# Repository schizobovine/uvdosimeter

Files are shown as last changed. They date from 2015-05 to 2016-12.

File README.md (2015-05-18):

# UV Dosimeter

Microcontroller project to (somehow) get data from the SiLabs SI1145 UV index
sensor to a user such that they know when the daystar is out to kill them
(slowly, with cancer).

Various designs in the works, but the primary focus right now is a Bluetooth
4.0+ LE based sensor which communicates to a smart phone or watch for data
logging and handling any user interaction/warnings. This cuts out the need for
a display, controls (beyond a power switch), and notification system.

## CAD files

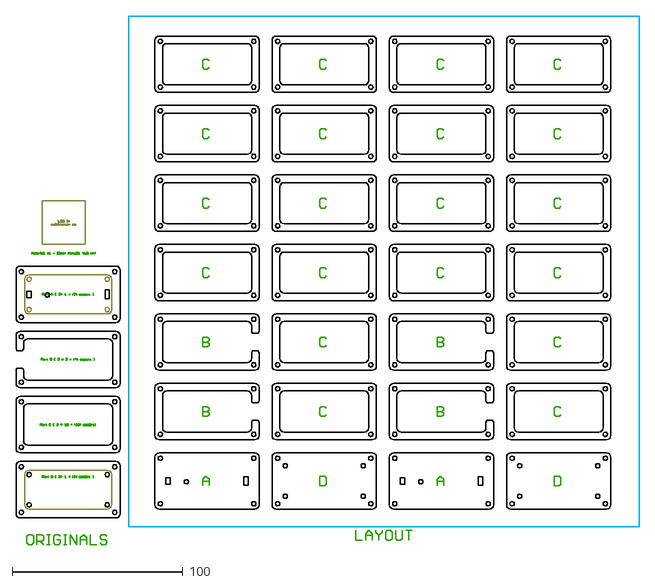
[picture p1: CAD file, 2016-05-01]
hardware/uv-dosimeter-featherwing-case-clear-pmma-1.5mm-mk-1.0.dxf
364.5 x 308.9

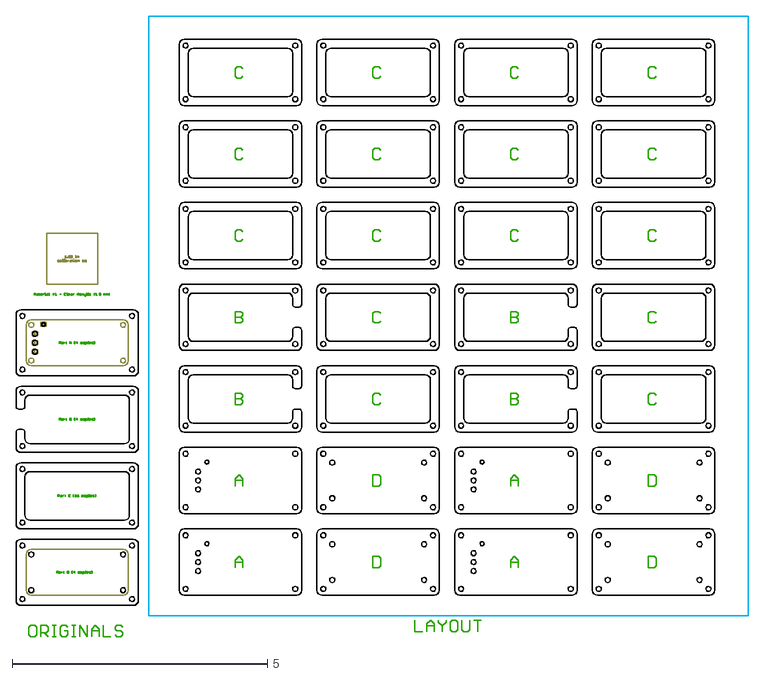
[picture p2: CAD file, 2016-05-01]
hardware/uv-dosimeter-featherwing-case-clear-pmma-1.5mm-mk-2.0.dxf
14.3 x 12.2

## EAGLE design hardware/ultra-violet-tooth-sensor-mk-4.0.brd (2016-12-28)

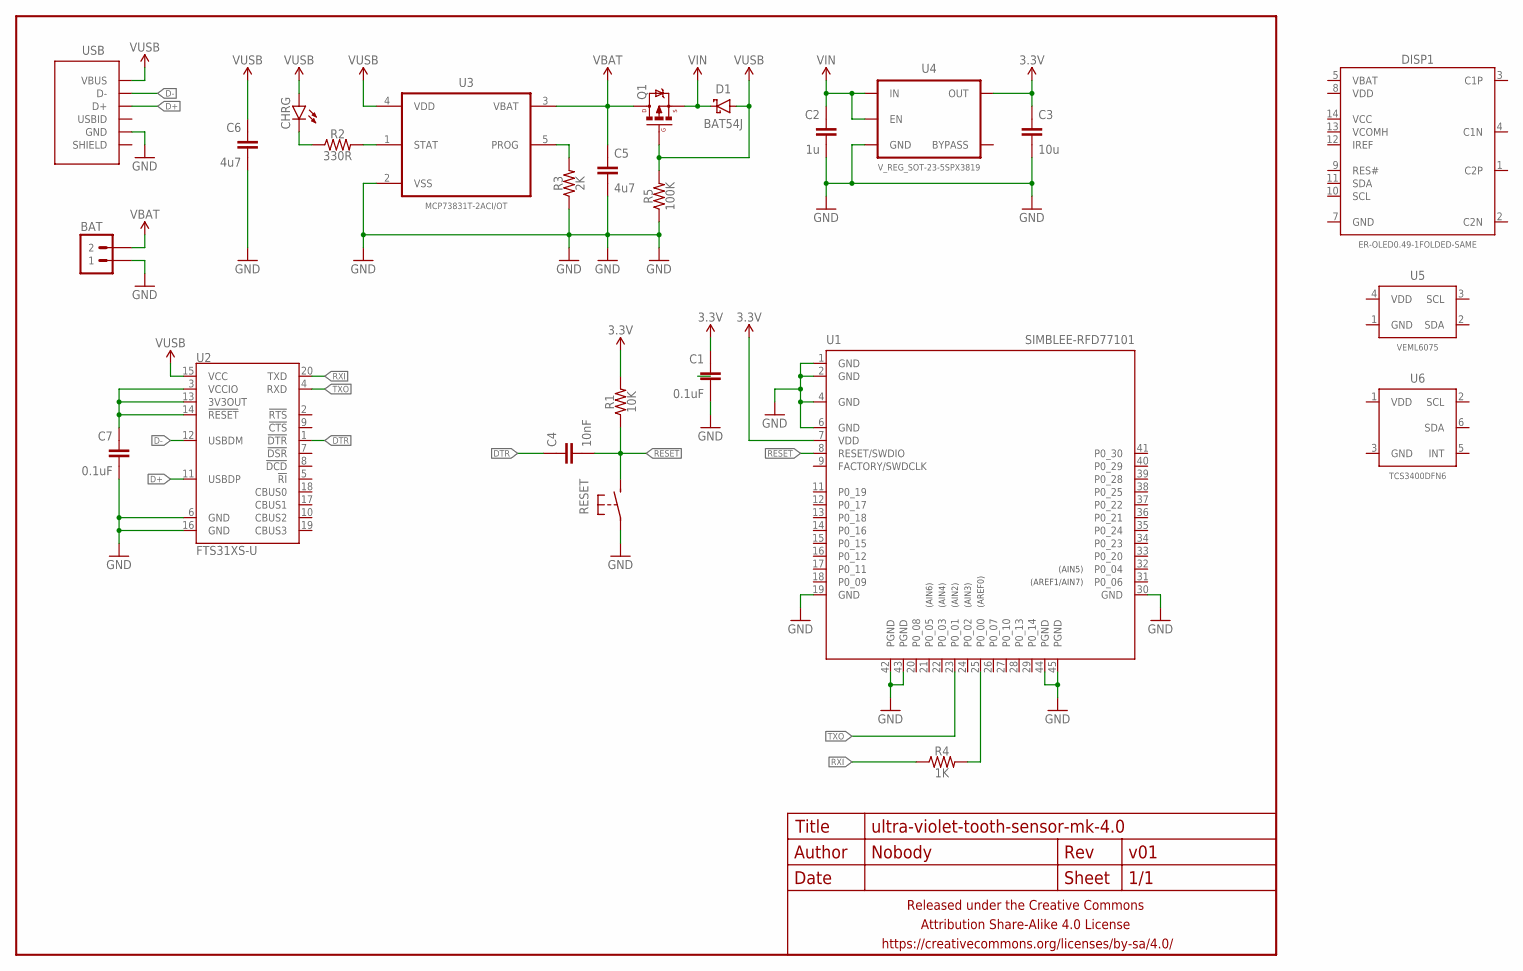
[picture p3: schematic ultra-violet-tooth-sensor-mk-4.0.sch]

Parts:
BAT: M02JST-2MM-SMT; JST-2-SMD
C1, C7: 0.1uF; C0402
C2: 1u; C0603-TIGHTER
C3: 10u; C0603-TIGHTER
C4: 10nF; C0402
C5, C6: 4u7; C0603-TIGHTER
CHRG: LED0603-TIGHT; LED-0603-TIGHT
D1: BAT54J; SOD323-SCHOTTKY
DISP1: ER-OLED0.49-1FOLDED-SAME; ER-OLED0.49-1-FOLDED-SAME
FRAME1: FRAME-LETTERNO_PACKAGE; DUMMY
Q1: MOSFET-PCHANNELSOT-23; SOT23
R1: 10K; R0402
R2: 330R; R0402
R3: 2K; R0402
R4: 1K; R0402
R5: 100K; R0402
RESET: SPST-NO-TACTSMD-TINIER; TACTILE_SWITCH_SMD_TINY
U1: SIMBLEE-RFD77101; RFD77101
U2: FTS31XS-U; SSOP20_L
U3: MCP73831T-2ACI/OT; SOT95P280X145-5N
U4: V_REG_SOT-23-5SPX3819; SOT23-5
U5: VEML6075; OPLGA4
U6: TCS3400DFN6; TCS3400_DFN6
USB: USB-AB-SHIELDFCI-10118193-USB-MICRO-B; FCI-10118193-USB-MICRO-B

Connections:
3.3V: C1.1, C3.1, R1.2, U1.7 (VDD), U4.5 (OUT)
!RESET: C4.2, R1.1, RESET.P$2 (2), U1.8 (RESET/SWDIO)
D+: U2.11 (USBDP), USB.3 (D+)
D-: U2.12 (USBDM), USB.2 (D-)
DTR: C4.1, U2.1 (!DTR)
GND: BAT.2 (1), C1.2, C2.2, C3.2, C5.2, C6.2, C7.2, R3.1, R5.1, RESET.P$1 (1), U1.1 (GND), U1.2 (GND), U1.4 (GND), U1.6 (GND), U1.19 (GND), U1.30 (GND), U1.42 (PGND), U1.43 (PGND), U1.44 (PGND), U1.45 (PGND), U2.6 (GND), U2.16 (GND), U3.2 (VSS), U4.2 (GND), USB.5 (GND)
unnamed: CHRG.C, R2.1
unnamed: R4.2, U1.25 (P0_00)
unnamed: C7.1, U2.3 (VCCIO), U2.13 (3V3OUT), U2.14 (!RESET)
unnamed: R3.2, U3.5 (PROG)
unnamed: R2.2, U3.1 (STAT)
RXI: R4.1, U2.20 (TXD)
TXO: U1.23 (P0_01), U2.4 (RXD)
VBAT: BAT.1 (2), C5.1, Q1.3 (D), U3.3 (VBAT)
VIN: C2.1, D1.C, Q1.2 (S), U4.1 (IN), U4.3 (EN)
VUSB: C6.1, CHRG.A, D1.A, Q1.1 (G), R5.2, U2.15 (VCC), U3.4 (VDD), USB.1 (VBUS)

Board: 2 copper layers, 26 parts (1 on the bottom side), 16 nets, no tracks yet.

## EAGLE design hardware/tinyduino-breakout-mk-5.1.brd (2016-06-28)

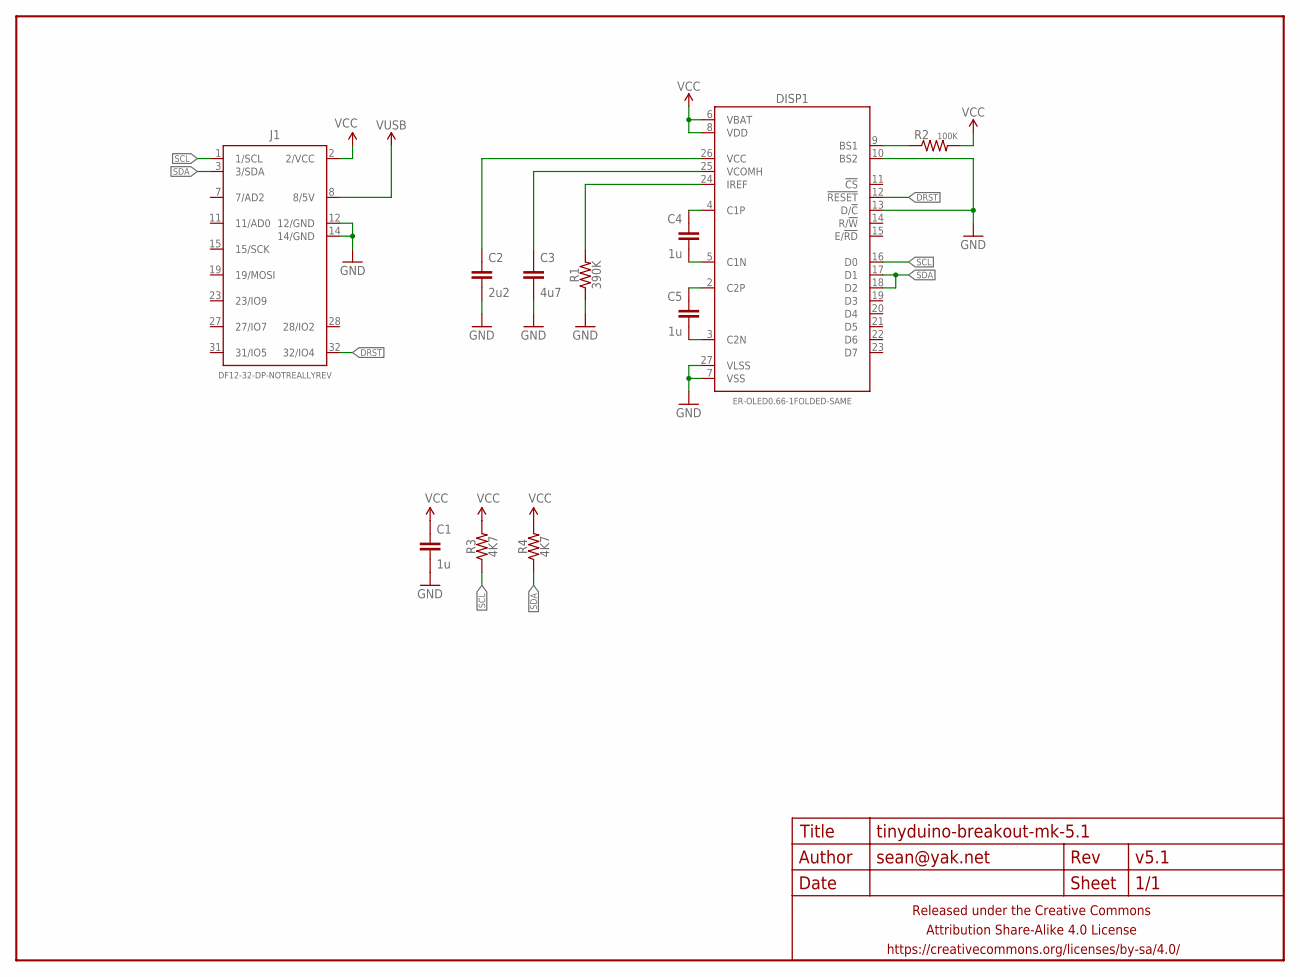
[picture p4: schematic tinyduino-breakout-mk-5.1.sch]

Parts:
C1, C4, C5: 1u; C0603
C2: 2u2; C0603
C3: 4u7; C0603
DISP1: ER-OLED0.66-1FOLDED-SAME; ER-OLED0.66-1-FOLDED-SAME
FRAME1: FRAME-LETTERNO_PACKAGE; DUMMY
J1: DF12-32-DP-NOTREALLYREV; DF12-32-DP-I2C+EXTRA-REV
R1: 390K; R0603
R2: 100K; R0603
R3, R4: 4K7; R0603

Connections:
DRST: DISP1.12 (!RESET), J1.32 (32/IO4)
GND: C1.2, C2.2, C3.2, DISP1.7 (VSS), DISP1.10 (BS2), DISP1.13 (D/!C), DISP1.27 (VLSS), J1.12 (12/GND), J1.14 (14/GND), R1.1
unnamed: C2.1, DISP1.26 (VCC)
unnamed: C3.1, DISP1.25 (VCOMH)
unnamed: DISP1.24 (IREF), R1.2
unnamed: C4.1, DISP1.4 (C1P)
unnamed: C4.2, DISP1.5 (C1N)
unnamed: C5.1, DISP1.2 (C2P)
unnamed: C5.2, DISP1.3 (C2N)
unnamed: DISP1.9 (BS1), R2.1
SCL: DISP1.16 (D0), J1.1 (1/SCL), R3.1
SDA: DISP1.17 (D1), DISP1.18 (D2), J1.3 (3/SDA), R4.1
VCC: C1.1, DISP1.6 (VBAT), DISP1.8 (VDD), J1.2 (2/VCC), R2.2, R3.2, R4.2
VUSB: J1.8 (8/5V)

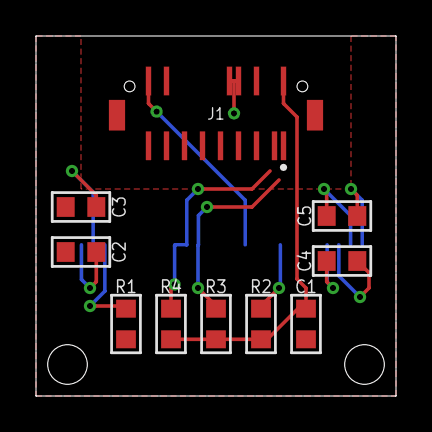
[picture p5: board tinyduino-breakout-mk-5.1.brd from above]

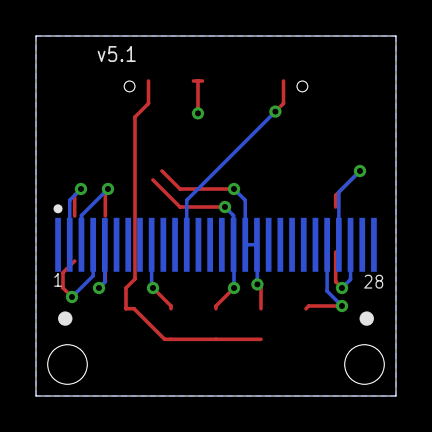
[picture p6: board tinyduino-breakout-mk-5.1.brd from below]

Board: 2 copper layers, 20.0 x 20.0 mm, 12 parts (3 on the bottom side), 13 nets.

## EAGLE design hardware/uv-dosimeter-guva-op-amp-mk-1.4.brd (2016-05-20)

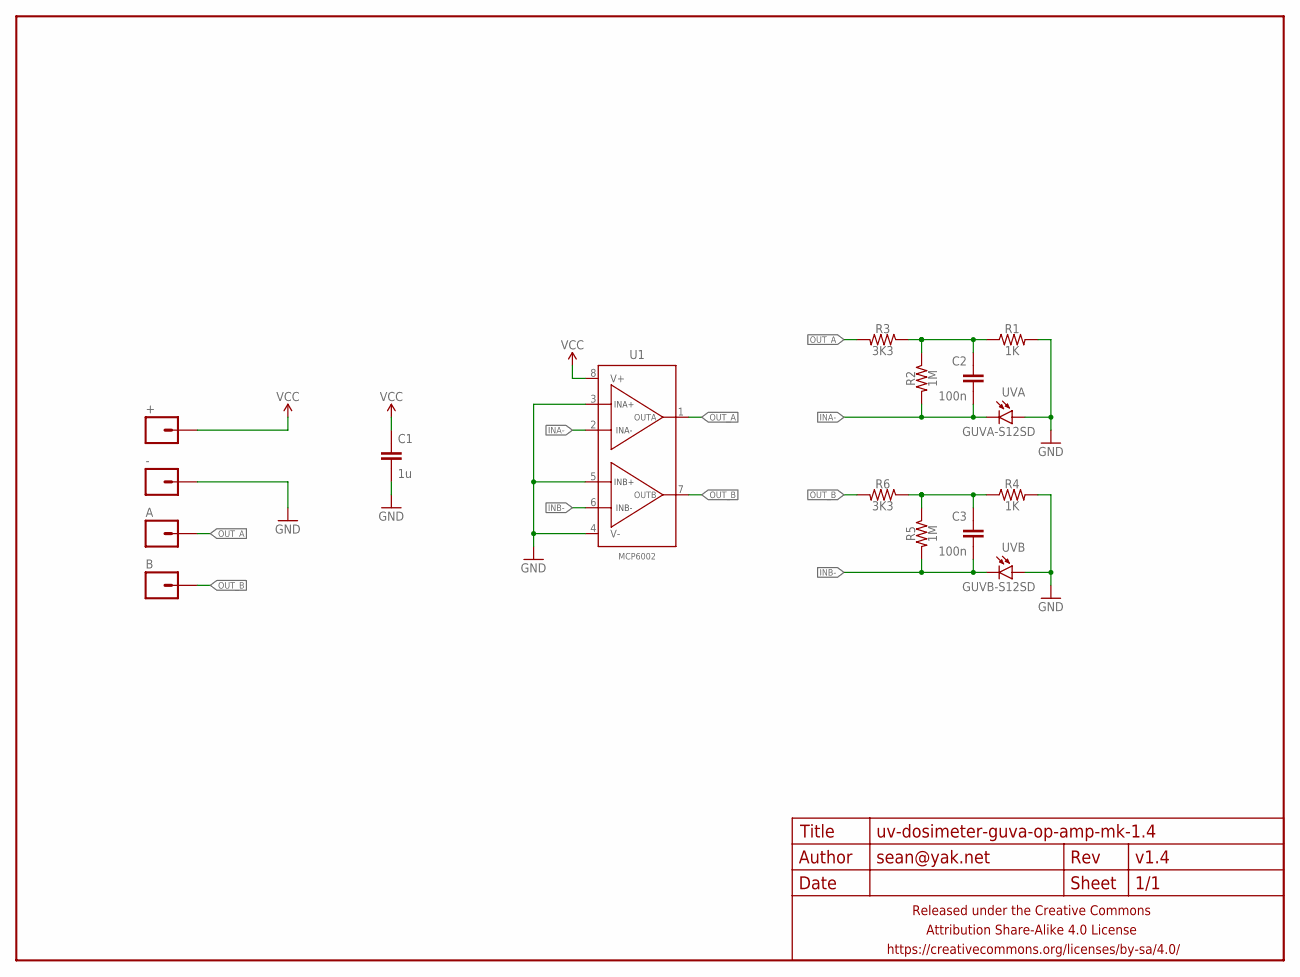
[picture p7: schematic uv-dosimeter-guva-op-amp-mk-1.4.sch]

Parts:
+: M01PTH; 1X01
-: M01PTH; 1X01
A: M01PTH; 1X01
B: M01PTH; 1X01
C1: 1u; C0603
C2, C3: 100n; C0603
FRAME1: FRAME-LETTERNO_PACKAGE; DUMMY
R1, R4: 1K; R0603
R2, R5: 1M; R0603
R3, R6: 3K3; R0603
U1: MCP6002; SO08
UVA: GUVA-S12SD; LED3528
UVB: GUVB-S12SD; LED3528

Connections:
GND: -.1, C1.2, R1.2, R4.2, U1.3 (INA+), U1.4 (V-), U1.5 (INB+), UVA.A, UVB.A
INA-: C2.2, R2.2, U1.2 (INA-), UVA.K (C)
INB-: C3.2, R5.2, U1.6 (INB-), UVB.K (C)
unnamed: C2.1, R1.1, R2.1, R3.1
unnamed: C3.1, R4.1, R5.1, R6.1
OUT_A: A.1, R3.2, U1.1 (OUTA)
OUT_B: B.1, R6.2, U1.7 (OUTB)
VCC: +.1, C1.1, U1.8 (V+)

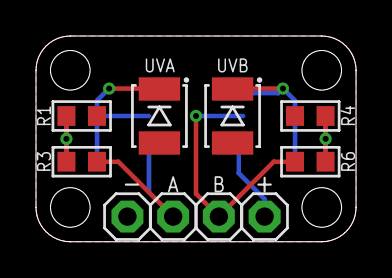
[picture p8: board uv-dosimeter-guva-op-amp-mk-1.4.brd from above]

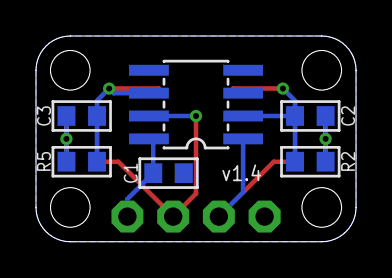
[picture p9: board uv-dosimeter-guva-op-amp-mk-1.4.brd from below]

Board: 2 copper layers, 17.8 x 11.4 mm, 17 parts (7 on the bottom side), 8 nets.

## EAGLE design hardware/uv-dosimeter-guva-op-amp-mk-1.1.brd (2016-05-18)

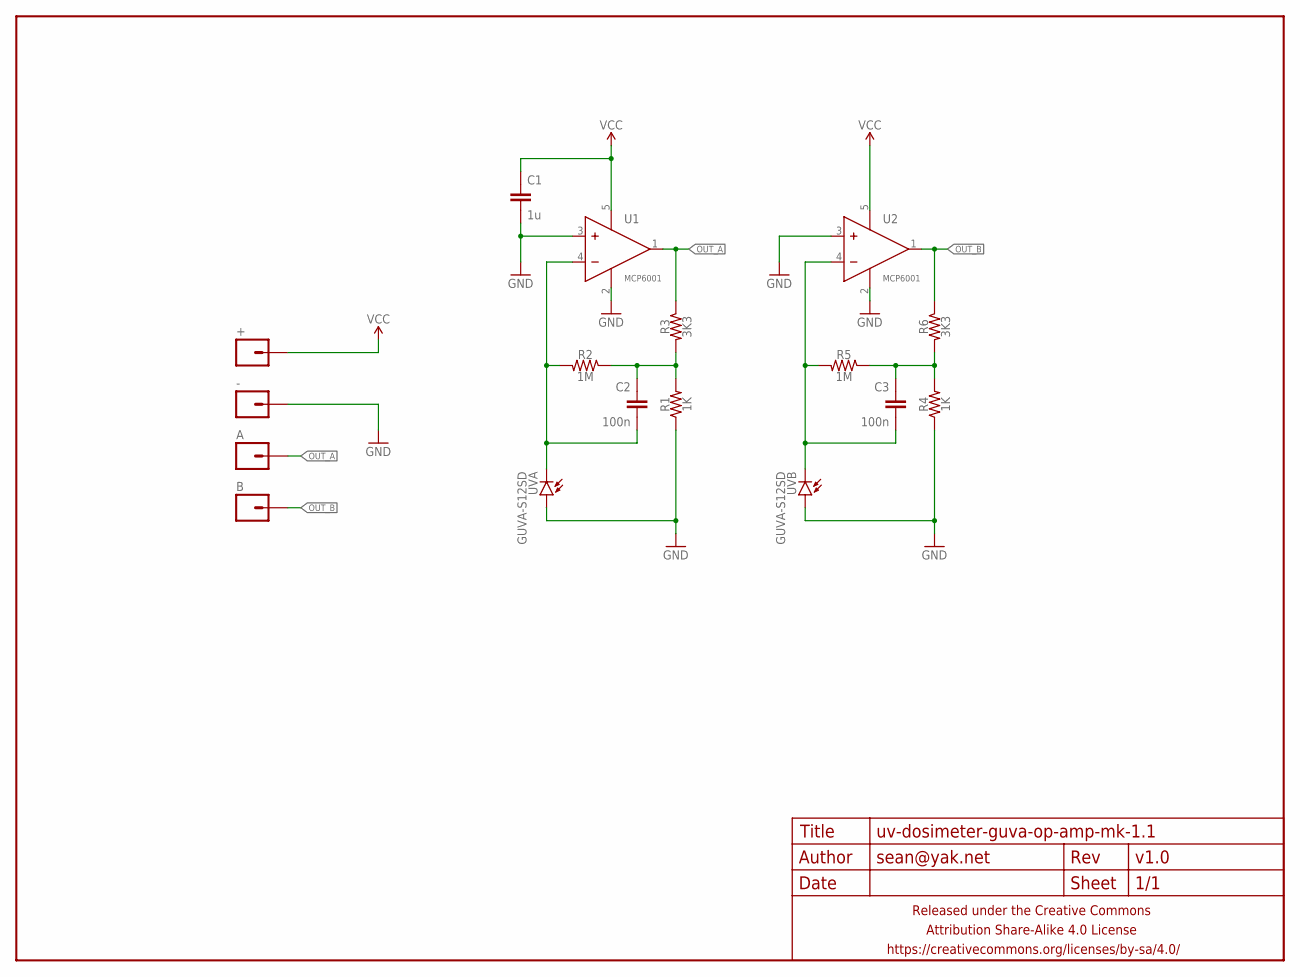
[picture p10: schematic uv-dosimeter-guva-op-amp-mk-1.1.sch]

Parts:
+: M01PTH; 1X01
-: M01PTH; 1X01
A: M01PTH; 1X01
B: M01PTH; 1X01
C1: 1u; C0603
C2, C3: 100n; C0603
FRAME1: FRAME-LETTERNO_PACKAGE; DUMMY
R1, R4: 1K; R0603
R2, R5: 1M; R0603
R3, R6: 3K3; R0603
U1, U2: MCP6001; SOT23-5
UVA: GUVA-S12SD; LED3528
UVB: GUVA-S12SD; LED3528

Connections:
GND: -.1, C1.2, R1.1, R4.1, U1.2 (V-), U1.3 (IN+), U2.2 (V-), U2.3 (IN+), UVA.A, UVB.A
unnamed: C2.1, R1.2, R2.1, R3.2
unnamed: C3.1, R4.2, R5.1, R6.2
NEG_FEED_A: C2.2, R2.2, U1.4 (IN-), UVA.K (C)
NEG_FEED_B: C3.2, R5.2, U2.4 (IN-), UVB.K (C)
OUT_A: A.1, R3.1, U1.1 (OUT)
OUT_B: B.1, R6.1, U2.1 (OUT)
VCC: +.1, C1.1, U1.5 (V+), U2.5 (V+)

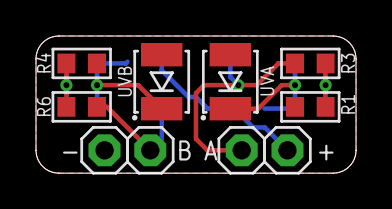
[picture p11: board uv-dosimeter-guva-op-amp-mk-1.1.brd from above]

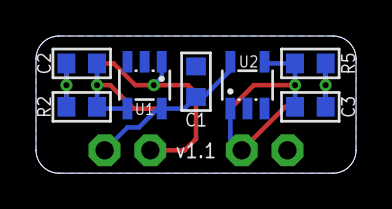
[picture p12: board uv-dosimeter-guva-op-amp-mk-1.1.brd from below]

Board: 2 copper layers, 17.8 x 7.6 mm, 18 parts (8 on the bottom side), 8 nets.

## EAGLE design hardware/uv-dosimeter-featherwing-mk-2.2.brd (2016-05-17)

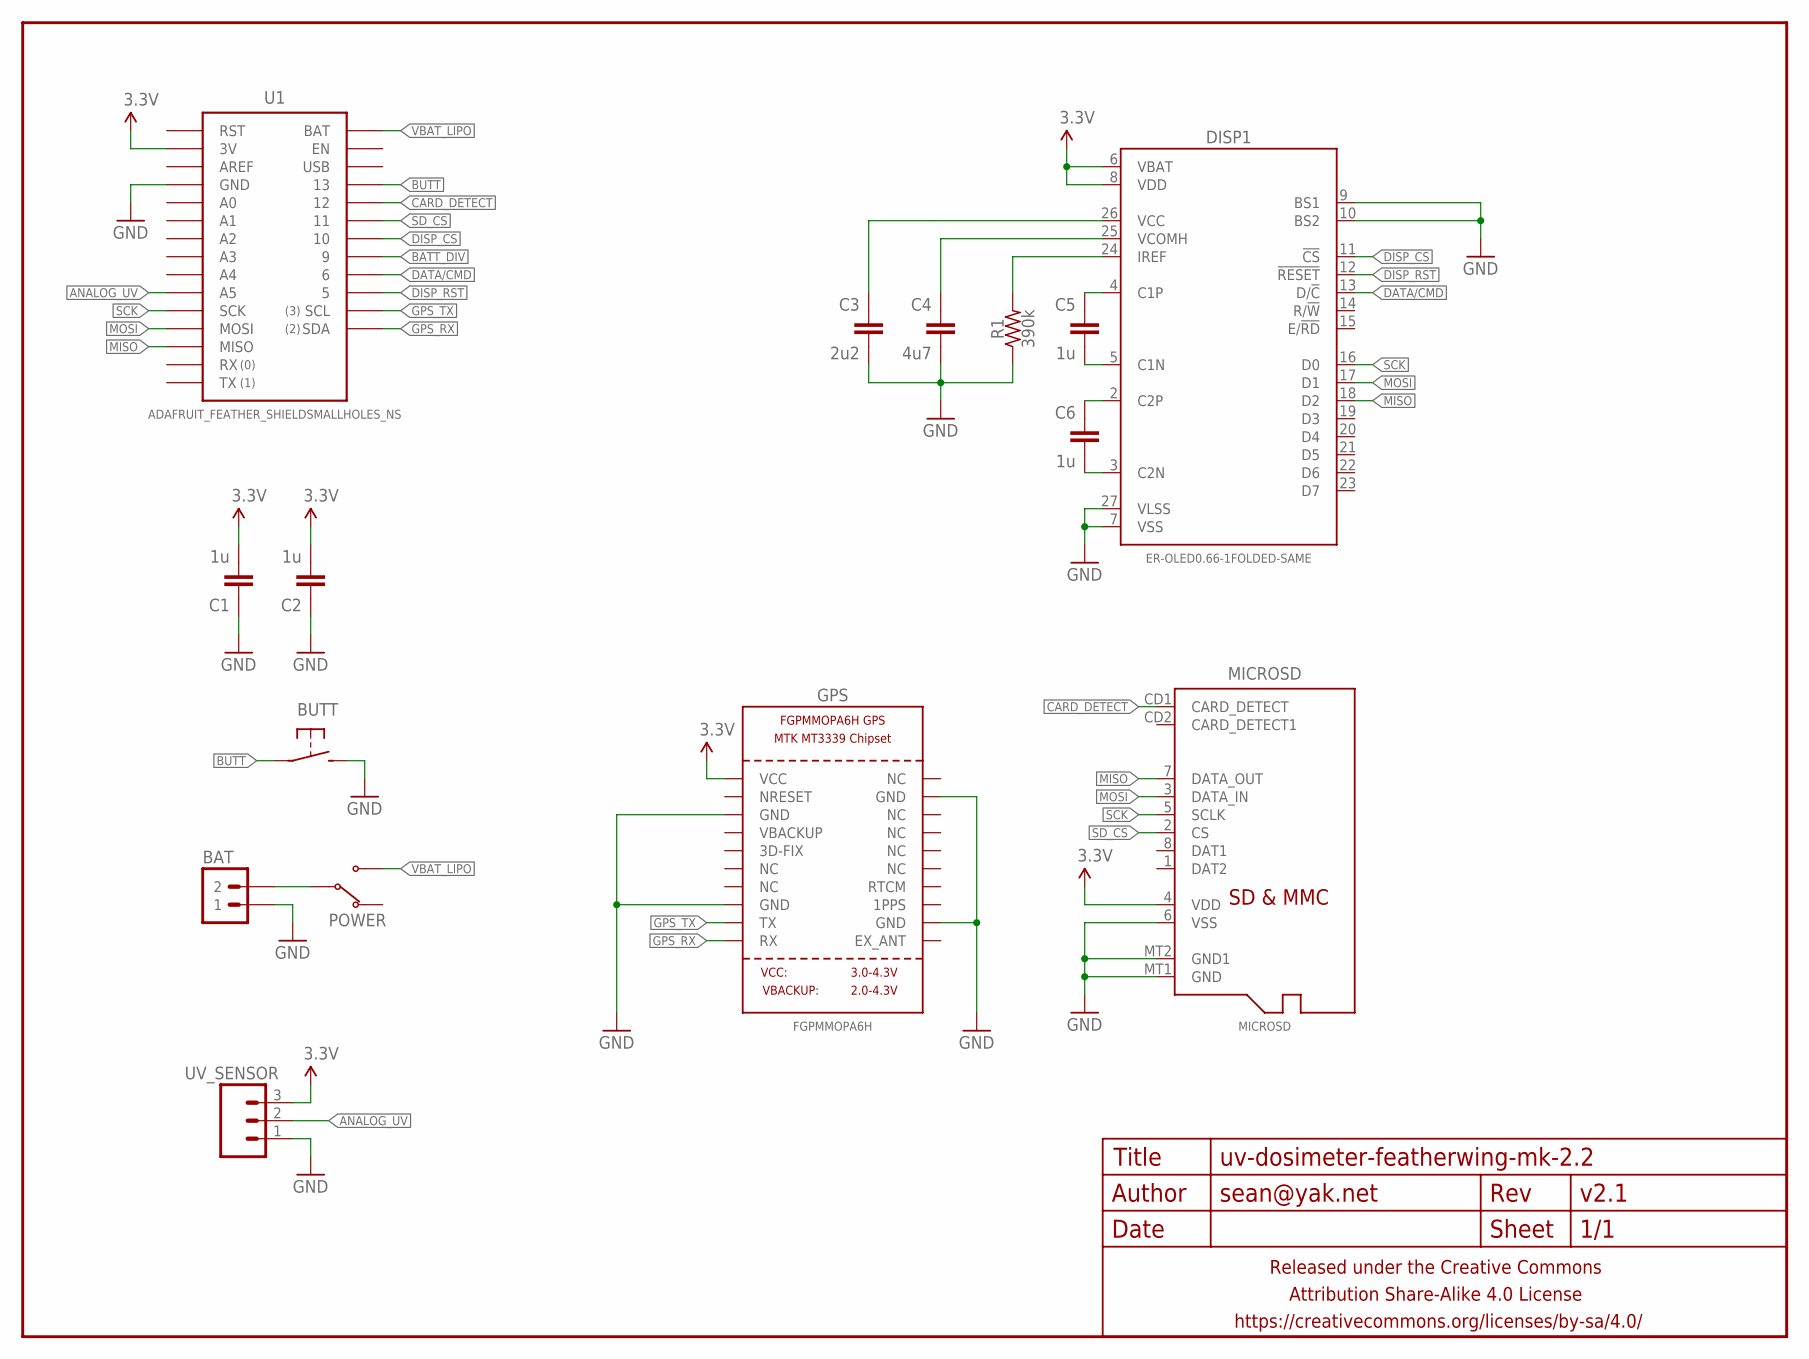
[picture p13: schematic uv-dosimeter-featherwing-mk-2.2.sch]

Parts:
BAT: M02JST-2MM-SMT; JST-2-SMD
BUTT: SPST-NO-TACT3MM-PTH-SMALL-PADS; DTS-3-SMALL-PADS
C1, C2, C5, C6: 1u; C0603
C3: 2u2; C0603
C4: 4u7; C0603
DISP1: ER-OLED0.66-1FOLDED-SAME; ER-OLED0.66-1-FOLDED-SAME
FRAME1: FRAME-LETTERNO_PACKAGE; DUMMY
GPS: FGPMMOPA6H
MICROSD: MICROSD
POWER: SWITCH-SPDTPTH-VERT-2.54MM; SWITCH-SPDT
R1: 390k; R0603
U1: ADAFRUIT_FEATHER_SHIELDSMALLHOLES_NS; ADAFRUIT_FEATHER_SMALLHOLES_NS
UV_SENSOR: M03PTH-CENTERED; 1X03-CENTERED

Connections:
3.3V: C1.2, C2.2, DISP1.6 (VBAT), DISP1.8 (VDD), GPS.P$1 (VCC), MICROSD.4 (VDD), U1.3V, UV_SENSOR.3
ANALOG_UV: U1.A5, UV_SENSOR.2
BATT_DIV: U1.9
BUTT: BUTT.1, U1.13
CARD_DETECT: MICROSD.CD1 (CARD_DETECT), U1.12
DATA/CMD: DISP1.13 (D/!C), U1.6
DISP_CS: DISP1.11 (!CS), U1.10
DISP_RST: DISP1.12 (!RESET), U1.5
GND: BAT.2 (1), BUTT.2, C1.1, C2.1, C3.2, C4.2, DISP1.7 (VSS), DISP1.9 (BS1), DISP1.10 (BS2), DISP1.27 (VLSS), GPS.P$3 (GND), GPS.P$8 (GND), GPS.P$12 (GND), GPS.P$19 (GND), MICROSD.6 (VSS), MICROSD.MT1 (GND), MICROSD.MT2 (GND1), R1.1, U1.GND@0 (GND), U1.GND@1 (GND), UV_SENSOR.1
GPS_RX: GPS.P$10 (RX), U1.SDA
GPS_TX: GPS.P$9 (TX), U1.SCL
MISO: DISP1.18 (D2), MICROSD.7 (DATA_OUT), U1.MISO
MOSI: DISP1.17 (D1), MICROSD.3 (DATA_IN), U1.MOSI
unnamed: C5.1, DISP1.4 (C1P)
unnamed: BAT.1 (2), POWER.2 (COM)
unnamed: C5.2, DISP1.5 (C1N)
unnamed: C6.1, DISP1.2 (C2P)
unnamed: C6.2, DISP1.3 (C2N)
unnamed: DISP1.24 (IREF), R1.2
unnamed: C4.1, DISP1.25 (VCOMH)
unnamed: C3.1, DISP1.26 (VCC)
SCK: DISP1.16 (D0), MICROSD.5 (SCLK), U1.SCK
SD_CS: MICROSD.2 (CS), U1.11
VBAT_LIPO: POWER.3 (NO), U1.BAT

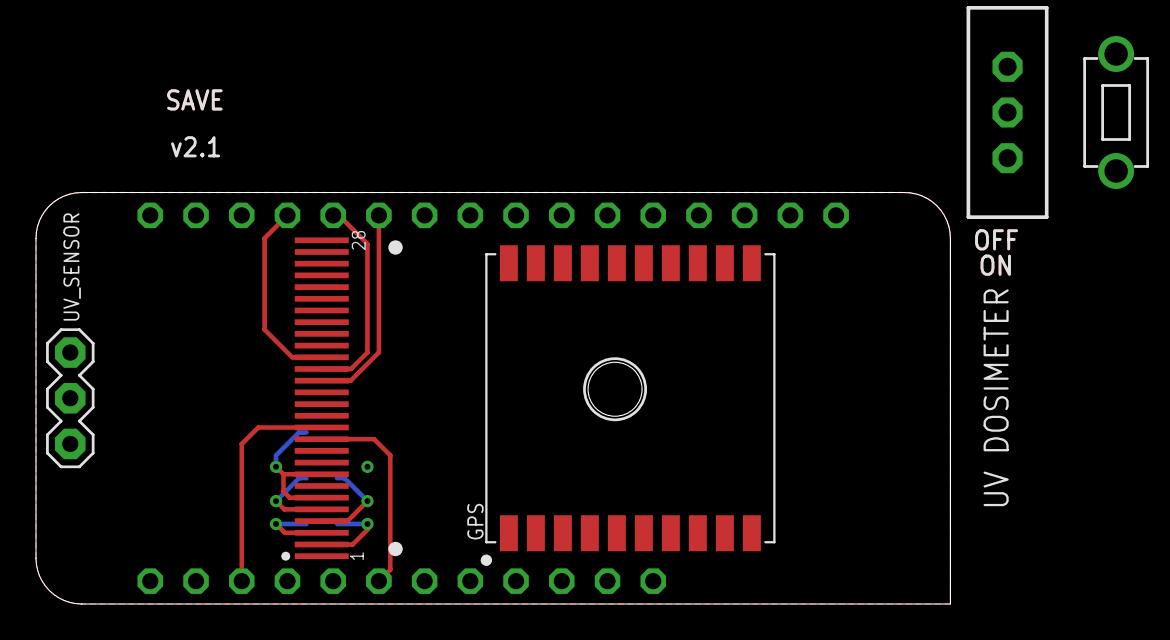
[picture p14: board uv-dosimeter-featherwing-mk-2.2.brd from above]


Board: 2 copper layers, 50.8 x 22.9 mm, 18 parts (12 on the bottom side), 23 nets.

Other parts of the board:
U$1: COW_SMALL
U$5: CC-BY-SA-4.0-NO-URL

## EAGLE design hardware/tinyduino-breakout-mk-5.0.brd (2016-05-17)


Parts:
FRAME1: FRAME-LETTERNO_PACKAGE; DUMMY
J1: DF12-32-DP-NOTREALLYREV; DF12-32-DP-I2C+EXTRA-REV
JP1: M05SMD-SHORT; 1X05-SMD-SHORT
LED1, LED2, LED3, LED4, LED5, LED6, LED7, LED8, LED9, LED10, LED11: LED0603; LED-0603
R1, R2, R3, R4: 100R; R0603

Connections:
GND: J1.12 (12/GND), J1.14 (14/GND), JP1.5
IO4: J1.32 (32/IO4), LED2.C, LED5.C, LED10.C, R2.1
IO5: J1.31 (31/IO5), LED3.C, LED9.C, LED11.C, R3.1
IO7: J1.27 (27/IO7), LED6.C, LED8.C, R4.1
IO9: J1.23 (23/IO9), LED1.C, LED4.C, LED7.C, R1.1
unnamed: LED1.A, LED2.A, LED3.A, R4.2
unnamed: LED4.A, LED5.A, LED6.A, R3.2
unnamed: LED7.A, LED8.A, LED9.A, R2.2
unnamed: LED10.A, LED11.A, R1.2
SCL: J1.1 (1/SCL), JP1.1
SDA: J1.3 (3/SDA), JP1.2
VCC: J1.2 (2/VCC), JP1.3

Board: 2 copper layers, 18 parts (4 on the bottom side), 12 nets, no tracks yet.

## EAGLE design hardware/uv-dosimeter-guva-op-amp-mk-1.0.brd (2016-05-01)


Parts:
C1: 100n; C0603
C2: CAPACITOR-CERAMICC0603; C0603
FRAME1: FRAME-LETTERNO_PACKAGE; DUMMY
JP1: M03PTH-CENTERED; 1X03-CENTERED
PD1: GUVA-S12SDLED3528; LED3528
R1: 1K; R0603
R2: 1M; R0603
R3: 3K3; R0603
U1: MCP6001SOT23-5; SOT23-5

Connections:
GND: C1.2, JP1.1, PD1.A, R1.1, U1.2 (V-), U1.3 (IN+)
unnamed: C2.1, R1.2, R2.2, R3.2
unnamed: C2.2, PD1.K (C), R2.1, U1.4 (IN-)
OUT: JP1.2, R3.1, U1.1 (OUT)
VCC: C1.1, JP1.3, U1.5 (V+)



Board: 2 copper layers, 50.8 x 22.9 mm, 11 parts (3 on the bottom side), 5 nets.

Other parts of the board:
U$1: COW_SMALL
U$5: CC-BY-SA-4.0-NO-URL

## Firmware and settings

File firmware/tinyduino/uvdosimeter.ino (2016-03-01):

/*
 * uvdosimeter.ino
 *
 * UV dosimeter based on Adafruit's Feather platform.
 *
 * Author: Sean Caulfield <sean@yak.net>
 *
 */

/*
#include <stdlib.h>
#include <stdio.h>
#include <string.h>
#include <math.h>
#include <avr/io.h>
#include <avr/pgmspace.h>
*/

#include <avr/io.h>
#include <avr/pgmspace.h>
#include <math.h>

#include <Arduino.h>
#include <Wire.h>
#include <Adafruit_SI1145.h>

#define SERIAL_DEBUG 0
#define SERIAL_SPEED 9600

//
// Tinyduino 16 LED Charliplexing Setup
//
//       I I I I I
//       O O O O O
//       5 6 7 8 9
// LED3  H   L
// LED4  L   H
// LED5    H L
// LED6    L H
// LED7    H   L
// LED8    L   H
// LED9  H     L
// LED10 L     H
// LED11     L H
// LED12     H L
// LED13     L   H
// LED14     H   L
//

const uint8_t NUM_LEDS = 12;

const uint8_t LED_LOW[NUM_LEDS] = {
  //6, // LED1  (unused)
  //5, // LED2  (unused)
  7, // LED3
  5, // LED4
  7, // LED5
  6, // LED6
  8, // LED7
  6, // LED8
  8, // LED9
  5, // LED10
  7, // LED11
  8, // LED12
  7, // LED13
  9, // LED14
  //8, // LED15 (unused)
  //9, // LED16 (unused)
};

const uint8_t LED_HIGH[NUM_LEDS] = {
  //5, // LED1  (unused)
  //6, // LED2  (unused)
  5, // LED3
  7, // LED4
  6, // LED5
  7, // LED6
  6, // LED7
  8, // LED8
  5, // LED9
  8, // LED10
  8, // LED11
  7, // LED12
  9, // LED13
  7, // LED14
  //9, // LED15 (unused)
  //8, // LED16 (unused)
};


// UV sensor
Adafruit_SI1145 si1145 = Adafruit_SI1145();

// Current UV index reading
uint8_t uvidx = 0;

// Microseconds since last reading
uint32_t last_reading = 0;

// Time (in microseconds) between readings
const uint32_t SENSE_INTERVAL_US = 1L << 20; // 1048576

// Time (in microseconds) to flash LEDs on for
const uint32_t LED_ON_US = 1L << 10; // 1024

////////////////////////////////////////////////////////////////////////
// HALPING
////////////////////////////////////////////////////////////////////////

void led_on(size_t lednum) {
  digitalWrite(LED_HIGH[lednum], HIGH);
  digitalWrite(LED_LOW[lednum], LOW);
  pinMode(LED_HIGH[lednum], OUTPUT);
  pinMode(LED_LOW[lednum], OUTPUT);
}

void led_off(uint8_t index) {
  pinMode(LED_HIGH[index], INPUT);
  pinMode(LED_LOW[index], INPUT);
  digitalWrite(LED_HIGH[index], LOW);
}

void led_all_off() {
  for (int i=5; i<10; i++) {
    pinMode(i, INPUT);
    digitalWrite(i, LOW);
  }
}

boolean is_reading_time() {
  uint32_t now = micros();
  uint32_t diff;

  // Attempt to handle under/overflow sanely
  if (now > last_reading) {
    diff = now - last_reading;
  } else {
    diff = now + (UINT32_MAX - last_reading);
  }

  if (diff > SENSE_INTERVAL_US) {
    last_reading = now;
    return true;
  } else {
    return false;
  }
}

////////////////////////////////////////////////////////////////////////
// SETUP
////////////////////////////////////////////////////////////////////////

void setup() {

#if SERIAL_DEBUG
  Serial.begin(SERIAL_SPEED);
#endif

  // Init charliplexing pins in high-Z state
  led_all_off();

  // Init i2C
  Wire.begin();

  // Init UV sensor
  si1145.begin();

  // More delay for supersitition?
  //delay(500);

}

////////////////////////////////////////////////////////////////////////
// MAIN LOOP
////////////////////////////////////////////////////////////////////////

void loop() {

  //
  // Only fetch readings once per SENSE_INTERVAL_US
  //
  if (is_reading_time()) {

    // Fetch & round sensor readings
    float uv = si1145.readUV() / 100.0;
    uvidx = (uint8_t)(0xFF & lround(uv));

#if SERIAL_DEBUG
    // Debug sensor readings
    Serial.print(F("UV "));
    Serial.print(uv, 2);
    Serial.print(F(" => "));
    Serial.println(uvidx);
#endif

  }

  //
  // Display UV index (0-11) via Charliplexed LEDs. Use a fixed time window for
  // the entire display, so that having more "dark" LEDs won't cause the
  // remaining ones to be brighter.
  //

  for (uint8_t i=0; i<NUM_LEDS; i++) {
    if (i <= uvidx) led_on(i);
    delayMicroseconds(LED_ON_US);
    if (i <= uvidx) led_off(i);
  }

}

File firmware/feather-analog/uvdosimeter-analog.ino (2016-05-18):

/*
 * uvdosimeter.ino
 *
 * UV dosimeter based on Adafruit's Feather platform.
 *
 * Author: Sean Caulfield <sean@yak.net>
 *
 */

/*
#include <stdlib.h>
#include <stdio.h>
#include <string.h>
#include <math.h>
#include <avr/io.h>
#include <avr/pgmspace.h>
*/

#include <Arduino.h>
#include <Wire.h>
#include <Adafruit_GFX.h>
#include <Adafruit_SSD1306.h>
#include <EnableInterrupt.h>
#include <Bounce2.h>

#define DISP_COLOR WHITE
#define DISP_MODE  SSD1306_SWITCHCAPVCC
#define DISP_ADDR  0x3C

#define BATT_DIV_PIN  9
#define BUTT_A        10
#define BUTT_B        6
#define BUTT_C        5
#define BUTT_INTERVAL 10
#define UV_SENSOR     A5

// Display controller
Adafruit_SSD1306 display = Adafruit_SSD1306();

// Buttons
Bounce buttA = Bounce();
Bounce buttB = Bounce();
Bounce buttC = Bounce();

////////////////////////////////////////////////////////////////////////
// HALPING
////////////////////////////////////////////////////////////////////////

float getBattVoltage() {
  pinMode(BATT_DIV_PIN, INPUT);
  delay(50);
  float measured = analogRead(BATT_DIV_PIN);
  pinMode(BATT_DIV_PIN, INPUT_PULLUP);
  return measured * 2.0 * 3.3 / 1024;
}

float getUVIndex() {
  float reading = analogRead(UV_SENSOR) / 1024.0 * 3.3;
  return reading / 0.1;
}

void textNormal() {
  display.setTextColor(WHITE);
}

void textInvert() {
  display.setTextColor(BLACK, WHITE);
}

////////////////////////////////////////////////////////////////////////
// INTERRUPTS
////////////////////////////////////////////////////////////////////////

void irqButtA() {
  buttA.update();
}

void irqButtB() {
  buttB.update();
}

void irqButtC() {
  buttC.update();
}

////////////////////////////////////////////////////////////////////////
// SETUP
////////////////////////////////////////////////////////////////////////

void setup() {

  // Avoid stupid with display/Serial/other hilarity
  delay(200);

  // Init i2C
  Wire.begin();

  // Init display
  display.begin(DISP_MODE, DISP_ADDR);
  display.clearDisplay();
  display.setTextSize(0);
  display.setTextColor(DISP_COLOR);
  display.print(F("UV Dosimeter"));
  display.setTextWrap(false);
  display.display();

  // Setup buttons & debouncing
  buttA.attach(BUTT_A, INPUT_PULLUP, BUTT_INTERVAL);
  buttB.attach(BUTT_B, INPUT_PULLUP, BUTT_INTERVAL);
  buttC.attach(BUTT_C, INPUT_PULLUP, BUTT_INTERVAL);

  // Attach interrupts so we can sleep more
  enableInterrupt(BUTT_A, irqButtA, CHANGE);
  enableInterrupt(BUTT_B, irqButtB, CHANGE);
  enableInterrupt(BUTT_C, irqButtC, CHANGE);

  // More delay for supersitition?
  delay(500);

}

////////////////////////////////////////////////////////////////////////
// MAIN LOOP
////////////////////////////////////////////////////////////////////////

void loop() {

  float uv = getUVIndex();
  float bat_v = getBattVoltage();

  //buttA.update();
  //buttB.update();
  //buttC.update();

  display.clearDisplay();

  //
  // Display sensor readings
  //

  display.setCursor(0, 0);
  display.setTextSize(2);
  display.print(F("UV "));
  display.print(uv, 2);

  display.setTextSize(0);
  display.setCursor(0, 16);
  display.print(F("Batt "));
  display.print(bat_v, 2);
  display.print(F("V"));

  //
  // Display button state
  //

  display.setCursor(110, 24);
  if (!buttA.read()) {
    textInvert();
  } else {
    textNormal();
  }
  display.print(F("A"));
  textNormal();

  display.setCursor(116, 24);
  if (!buttB.read()) {
    textInvert();
  } else {
    textNormal();
  }
  display.print(F("B"));
  textNormal();

  display.setCursor(122, 24);
  if (!buttC.read()) {
    textInvert();
  } else {
    textNormal();
  }
  display.print(F("C"));
  textNormal();

  // Display refresh
  display.display();

  delay(1000);

}

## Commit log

2015-05-28 boards for first manufacture run
    [ultra-violet-tooth-sensor-mk-2.2.brd, ultra-violet-tooth-sensor-mk-2.2.sch]
2015-06-01 many new tries, but going with mk 3.2 for next batch to oshpark
    [ultra-violet-tooth-sensor-mk-2.3.brd, ultra-violet-tooth-sensor-mk-2.3.sch, ultra-violet-tooth-sensor-mk-2.4.brd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]
2015-06-01 more dicking around
    [ultra-violet-tooth-sensor-mk-3.3.brd, ultra-violet-tooth-sensor-mk-3.3.sch]
2015-06-22 more tweaking/twaddling
    [ultra-violet-tooth-sensor-mk-3.3.brd, ultra-violet-tooth-sensor-mk-3.3.sch]
2015-07-18 swap to adafruit SD library for bit-banging; python script to handle initial time-setting
    [timeset.py]
2016-01-15 switching to 128x32 version
2016-01-18 various attempts at a case for this thing
    [case-for-feather-mk-1.0.brd]
2016-01-18 power switchen
    [feather-power-switch-mk-1.0.brd, feather-power-switch-mk-1.0.sch, feather-power-switch-mk-2.0.brd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]
2016-01-18 adding revision number to file name
    [tinyduino-breakout-mk-1.0.brd, tinyduino-breakout-mk-1.0.sch]
2016-01-18 adding revsion info to schematic and board
    [tinyduino-breakout-mk-1.0.brd, tinyduino-breakout-mk-1.0.sch]
2016-01-18 new revision for new year
    [tinyduino-breakout-mk-2.0.brd, tinyduino-breakout-mk-2.0.sch]
2016-01-18 tiny breakout attempt
    [tinyduino-breakout-mk-2.0.brd, tinyduino-breakout-mk-2.0.sch]
2016-02-28 refinements to connector for tinyduino
    [tinyduino-breakout-mk-2.1.brd, tinyduino-breakout-mk-2.1.sch, tinyduino-breakout-mk-3.0.brd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]
2016-02-28 simple 0-11 display using charliplexed leds
2016-03-01 mark4, back to the full size breakout
    [tinyduino-breakout-mk-4.0.brd, tinyduino-breakout-mk-4.0.sch]
2016-03-02 finished layout but unhappy w/choices
    [tinyduino-breakout-mk-4.0.brd, tinyduino-breakout-mk-4.0.sch]
2016-03-02 relayout of charliplexed display only with 12 leds and connector for uv sensor (but nothing else
    [tinyduino-breakout-mk-4.1.brd, tinyduino-breakout-mk-4.1.sch]
2016-04-16 featherwings to use sparkfun's microview plus adafruit's feather + uv sensor
    [uv-dosimeter-featherwing-mk-1.0.brd, uv-dosimeter-featherwing-mk-1.0.sch, uv-dosimeter-featherwing-mk-1.1.brd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]
2016-05-01 new layouts for featherwing
    [uv-dosimeter-featherwing-mk-1.3.brd, uv-dosimeter-featherwing-mk-1.3.sch, uv-dosimeter-featherwing-mk-2.0.brd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]
2016-05-01 first pass attempt at the opamp circuit for this UV photodiode
    [uv-dosimeter-guva-op-amp-mk-1.0.brd, uv-dosimeter-guva-op-amp-mk-1.0.sch]
2016-05-01 drawings and autocad exports for laser-cut acrylic case
    [uv-dosimeter-featherwing-case-clear-pmma-1.5mm-mk-1.0.brd, uv-dosimeter-featherwing-case-clear-pmma-1.5mm-mk-1.0.dxf, uv-dosimeter-featherwing-case-clear-pmma-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]
2016-05-01 jesus h christ this is a stupid limitation of the arduino gui
2016-05-01 to make the arduino gui less stupid
2016-05-03 removing these don't need 'em
    [uv-dosimeter-featherwing-mk-3.0.brd, uv-dosimeter-featherwing-mk-3.0.sch]
2016-05-17 new bards
    [tinyduino-breakout-mk-4.2.brd, tinyduino-breakout-mk-4.2.sch, tinyduino-breakout-mk-4.3.brd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]
2016-05-18 initial layout for UVA/B sensor board
    [uv-dosimeter-guva-op-amp-mk-1.1.brd, uv-dosimeter-guva-op-amp-mk-1.1.sch]
2016-05-20 various relayouts of the opamp
    [uv-dosimeter-guva-op-amp-mk-1.2.brd, uv-dosimeter-guva-op-amp-mk-1.2.sch, uv-dosimeter-guva-op-amp-mk-1.3.brd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]
2016-06-28 breakouts for the tinyduino version
    [tinyduino-breakout-mk-5.1.brd, tinyduino-breakout-mk-5.1.sch]
2016-07-26 UV sensor testing firmware
2016-08-01 testing against other sensors
2016-08-01 simblee based uvdosimeter
    [ultra-violet-tooth-sensor-mk-4.0.brd, ultra-violet-tooth-sensor-mk-4.0.sch]
2016-08-02 more fiddling, need smaller usb to uart chip
    [ultra-violet-tooth-sensor-mk-4.0.brd, ultra-violet-tooth-sensor-mk-4.0.sch]
2016-12-28 new board work
    [ultra-violet-tooth-sensor-mk-4.0.brd, ultra-violet-tooth-sensor-mk-4.0.sch]

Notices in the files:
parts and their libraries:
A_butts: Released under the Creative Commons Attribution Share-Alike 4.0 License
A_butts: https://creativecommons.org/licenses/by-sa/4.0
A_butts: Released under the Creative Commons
